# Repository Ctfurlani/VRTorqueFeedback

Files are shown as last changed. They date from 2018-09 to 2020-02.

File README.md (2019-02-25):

# VRTorqueFeedback
Software and Hardware to emulate haptic feedback of weighted objects in 
VR.

## Principle Of Operation
The idea is that the pointer (sometimes refered to as "feedback" in the 
code) moves/rotates in order to shift the center of mass of the
controller. This creates a torque that mimics the direction and
intensity of the one that would be exerted by the virtual object being
held.



## Calculating Pointer Position
If we imagine the feedback stem/pointer as a vector in R3, we can define
references and directions of motion to use in our program. In "home"
position, the vector points up, aligned with the Y axis. From this
position, it can rotate alpha degrees around the X axis, and Gamma
degrees around the Z axis, reaching any position in a hemisphere of
positive Y values.

We gain ease of understanding and implementation by decomposing the
ideal torque in two components Tx and Tz (projections over the X and Z
axis). To emulate Tx and Tz on the user's hand, the feedback must rotate
alpha degrees around X (for Tx), and gamma degrees around Z (for Tz).
The combination of these two rotations yields the sum of Tx and Tz,
which is the real torque T.

 

Ideal torque T will be achieved if and only if the pointer is rotated by
alpha and gamma, so the problem lies in calculating these two angles.
Luckily, the decomposition chosen facilitates this task by letting us
analyse torque decompositions with coplanar vectors *Rx*,*Wx* and *Rz*,
*Wx* - projections of R and W on X and Z.

We obtain ideal torque vector directly with

<!-- **T** = **R** x **W** -->
 

Then, we split it in two components, projections on X and Z:

<!-- TprojX = **T** . **X** = |**Tx**| * signX, where signX is 1 or -1 -->
 

<!-- TprojZ = **T** . **Z** = |**Tz**| * signZ, where signX is 1 or -1 -->
 

Where signx and signz follow the rule
 

We obtain the angles alpha' ang gamma' from the cross product magnitude
formula and considering that dot product is a linear operation (used to
calculate **Tx** and **Tz**).

<!-- |**Tx**| = |**Rx**| * |**Wx**| * sin(alpha') , where a E [0, 90] -->
 

<!-- |**Tz**| = |**Rz**| * |**Wz**| * sin (gamma') , where g E [0, 90] -->
 

 

We then solve for alpha' and gamma', while substituting |**Wx**| =
|**Wz**| = |**W**| for m * g (to account for real feedback weight);
|**Rx**| for rx * l; and |**Rz**| for rz * l (to account for real
feedback length, but keeping proportions between **Rx** and **Rz**).

<!-- alpha' = arcsin((|**Tx**|) / |**Rx**| * l * m * g) -->
 

<!-- gamma' = arcsin((|**Tz**|) / |**Rz**| * l * m * g) -->
 

 

We could simplify l * m * g to a single constant c, but it's useful to
have it separated into the two tangible variables l and m because of the
attribution of weights and distances in metric units in the virtual
scenario (in Unity they are actually dimensionless, but if we assume
meters for distance, we must also assume kilograms for mass).

Finally, we obtain alpha and gamma from alpha' and gamma', attributing
it the correct signs to achieve full hemispherical reach.

<!-- alpha = alpha' * signX, where alpha E [-90, 90] -->
 

<!-- gamma = gamma' * signZ, where gamma E [-90, 90] -->
 

 

### "Neutralizing" Center of Mass
When the user is not holding any object, the program can rotate the
feeeback pointer so that it shifts the controller's center of mass to a
position where (ideally) no torque would be exerted over the player's
hand. The heuristic to achieve this effect is to rotate the pointer
according to the rotation of the controller, in the opposite direction
of rotation around X and Z axes. As an example, if the user tilts the
controller by 30 degrees around the X axis and 45 degrees around the Z
axis, the pointer will rotate by -30 and -45 degrees (maybe multiplied
by a proportionality constant) around X and Z to compensate.

 

## Obtaining Angles for Servos
The angles alpha and gamma are not the ones to be used by the servo
motors. This is because the two DoFs of the motors are not the same as
the ones used in our previous calculations (rotations around X and Z
axes). The servos combine theta (angles from Z in the XZ plane) and phi
(angles from Y axis) rotations in spherical coordinates, with fixed
radius. This angles must be derived unambiguously from the position of
the feedback pointer, to provide the mirroring from the virtual pointer
to the real one.

<p align="center">
     
    
</p> 

## Moving the Servos
Movement of the servo motors is coordinated by the ARDUnity plugin. With
its "wire editor", we create a serial communication bridge between Unity
and an arduino. The serial communication transmits data to coordinate
two servos (represented by two "Generic Servo" components), which get
the desired angle of rotation from a direct mapping of the rotation of a
virtual object (with the components/scripts "Rotation Axis Reactor").
With this setup, to achieve rotations by X degrees in a servo, we simply
rotate a linked virtual object by X degrees in a set direction. In our
scene, these objects are the "Mirror Servo Theta" and "Mirror Servo
Phi".

<p align="center">
    
    
</p>

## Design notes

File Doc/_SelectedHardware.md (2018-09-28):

# Prototype 0 Hardware List

|Part |Quantity |Buy/Print  |File Name (inside Prototype1/Prototype0) |Link |
|---	 |:---:	 |:---: |---	 |---	 |
|Hitec HS-311 Servo |1 	 |Buy* |servo_hs_311 |https://goo.gl/PXjvbA  |
|Screw 04** - Lenght 0.1875" (3/16") |4 	 |Buy |actobotics/screw_632104 |https://goo.gl/LqVes7  |
|Screw 06** - Lenght 0.250" (1/4") |2 	 |Buy |actobotics/screw_632106 |https://goo.gl/LqVes7  |
|Screw 08** - Length 0.3125" (5/16") |2 	 |Buy |actobotics/screw_632108 |https://goo.gl/LqVes7  |
|Screw 10** - Length 0.375" (3/8") |3 	 |Buy |actobotics/screw_632110 |https://goo.gl/LqVes7  |
|Screw 20** - Length 0.750" (3/4") |2 	 |Buy |actobotics/screw_632120 |https://goo.gl/LqVes7  |
|Nut**	 |5 	 |Buy |actobotics/nut |https://goo.gl/WMunDN  |
|Std-Servo Plate A |1 	 |Print |actobotics/servo_plate_standard_a.par |https://goo.gl/hHZ4xE  |
|Hub Horn (disk) |2 	 |Print |actobotics/disco_hub_1.par |https://goo.gl/RcKKAo  |
|Pattern Bracket |1 	 |Print |actobotics/pattern_bracket_standard.par |https://goo.gl/cb6QCk  |
|Side Mount B |1 	 |Print |actobotics/side_mount_b.par |https://goo.gl/otaodq  |
|Aluminum Beam 6-16 |1 	 |Print |actobotics/beam_aluminum_vertical.par |https://goo.gl/EDe8Bq  |
|Custom Spacer |1 	 |Print |custom/custom_spacer |- |	

*Price: R$ 56,90 + R$ 20.90 (shipping)

**Thread size 6-32





# Prototype 1 Hardware List

## 3D print
### Strap
-  https://www.thingiverse.com/thing:1959237

    

- 3D print https://www.thingiverse.com/thing:2713178

    

### Shell
- 3D print shell coupled to strap

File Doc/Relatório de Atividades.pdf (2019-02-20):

# Relatório de Atividades

### Bolsa de Iniciação Científica CNPq

# 1. Identificação

## 1.1. Dados de Identificação do Projeto

Título do Projeto: Emulação de Torque em Ambientes de Realidade Virtual Vigência da Bolsa: 01/08/2018 a 28/02/2019
Período do Relatório: 01/08/2018 a 28/02/2019
Orientador: Prof. Dr. Anderson Maciel

## 1.2. Dados de Identificação do Bolsista

Nome: Gabriel de Souza Seibel
Vínculo Acadêmico: UFRGS - Graduando em Engenharia de Computação CPF: 872.043.550-91

# 2. Introdução

Interações entre usuários e ambientes de realidade virtual se baseiam, atualmente, em informações visuais e auditivas. O usuário, com a tecnologia de rastreamento atual, é capaz de manipular objetos virtuais através do uso de controles como o do HTC VIVE. Contudo, esse modelo deixa a desejar quanto ao potencial de imersão e realismo, pela falta de estímulos hápticos com os quais os humanos estão acostumados.
O projeto em questão tem como objetivo enriquecer interações com ambientes de realidade virtual através da criação de um acessório para o controle do HTC VIVE que provoca no usuário a impressão de que objetos manipulados causam torque em suas mãos (como acontece naturalmente na realidade). O uso do dispositivo proposto tem potencial não somente aumentar a imersão dos usuários, mas também de proporcionar manipulações mais precisas. O efeito de torque sobre a mão humana é atingido pelo deslocamento do centro de massa do acessório fixado ao controle que o usuário segura. Para tanto, o funcionamento do dispositivo é baseado em dois motores que giram e deslocam, nos limites de um hemisfério, uma haste com a ponta pesada.

# 3. Materiais e Métodos

O desenvolvimento do projeto se deu em etapas distintas; cada uma será abordada a seguir, aproximadamente em ordem cronológica. O progresso da implementação foi constantemente reportado e discutido com o professor orientador, de modo que passos seguintes pudessem ser estabelecidos de maneira eficiente e com segurança.

## 3.1. Definição e Modelagem do Problema e da Solução

Em um primeiro momento, foi necessário definir precisamente qual seria a motivação e o objetivo do projeto. O produto foi imaginado de maneira relativamente precisa, e sua especificação de funcionamento foi definida em vários aspectos. A interação entre motores e o ambiente virtual foi minuciosamente planejada, evidenciando as ferramentas, as abstrações e os cálculos matemáticos a serem empregados na implementação do objetivo principal (a emulação de torques causados por objetos que o usuário segura).
Nesta etapa, foram elencados itens essenciais para a realização do projeto: dois servos motores, um simulador na plataforma Unity, uma placa Arduino (para controle dos servos e comunicação com a Unity) e uma “presilha” para acoplar os servos e a placa no controle do HTC VIVE de forma modular e prática (este item seria confeccionado no laboratório com o auxílio de uma impressora 3D).

## 3.2. Estudo de Trabalho Prévio e Ferramentas

Com o problema e a solução mais precisamente delineados, partiu-se para o estudo de um trabalho prévio de outra bolsista no mesmo projeto. Esta etapa foi importante pela identificação de ferramentas auxiliares que poderiam ser utilizadas para facilitar o desenvolvimento. Mais precisamente, foi entendido que a maneira mais prática de integrar a placa Arduino com a Unity seria usando um plugin que a bolsista havia prospectado e explorado - chamado ARDUnity.
Em seguida, alguns dias foram dedicados ao aprendizado do uso da Unity, através de vídeos tutoriais e implementações de jogos e simulações simples. Houve, concomitantemente, familiarização com a linguagem de programação C#, empregada para a criação dos projetos de estudo. Mais adiante, o plugin SteamVR foi testado e explorado para que houvesse a integração do HTC VIVE com a simulação a ser implementada. Também foi atestado o funcionamento do plugin ARDUnity, comprovando a comunicação efetiva entre o software e o microprocessador da placa.

## 3.3. Hardware

### 3.3.1. Circuito Elétrico

A fim de proporcionar o funcionamento correto, seguro e performaticamente satisfatório dos servos motores, foi necessário elaborar um circuito elétrico simples envolvendo esses componentes, o Arduino e baterias. O circuito originalmente foi imaginado sobre uma placa de prototipação (documentado utilizando o software Fritzing, como mostra a Figura 1), mas em iterações posteriores alguns fios foram soldados e arranjados de forma que a protoboard não fosse mais necessária.

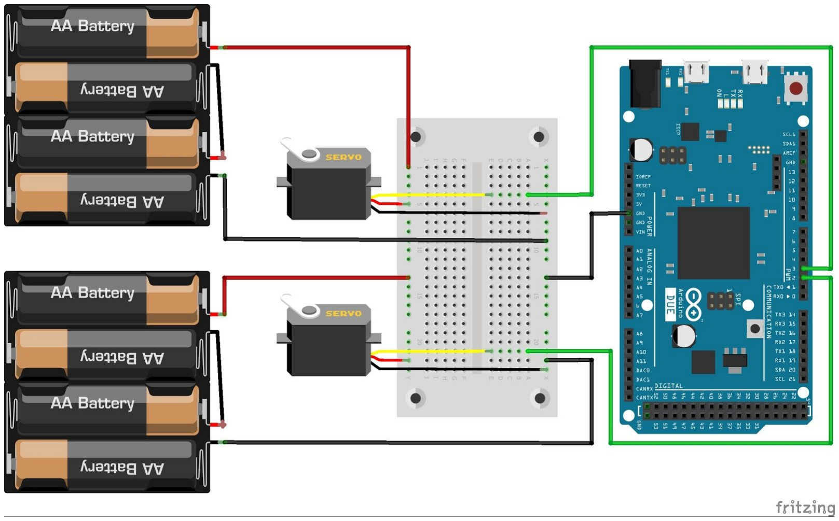
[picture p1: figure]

Figura 1 - Protótipo de circuito no software Fritzing.

Também foi explorado o funcionamento de um componente eletrônico que provesse comunicação sem fio entre o Arduino e o computador onde é executada a simulação, para ser usada em vez da comunicação por cabo USB. Apesar de atestado o funcionamento do novo meio de comunicação, o desenvolvimento dessa funcionalidade foi postergado devido a impossibilidade de integração do módulo com a Unity em um curto espaço de tempo sem que fosse paga uma taxa pelo serviço do plugin ARDUnity.

### 3.3.2. Peças Rígidas - Impressora 3D

Tendo pronta a integração entre os motores e o software, era chegado o momento de criar partes rígidas que tornassem o produto integrável ao controle do VIVE. A modelagem das peças foi realizada no software Solid Edge (como mostra a Figura 2), após uma etapa de aprendizado do uso da ferramenta através de vídeos e tutoriais práticos. Dificuldades e dúvidas pontuais do uso do programa (e futuramente da impressora 3D) foram resolvidas recorrendo ao auxílio de um mestrando do laboratório que possuía experiência na área.
Em um primeiro momento, foram modeladas partes para fixar um motor ao outro, associando seus eixos de rotação de modo que a haste pudesse ser girada até qualquer ponto de uma semi-esfera imaginária (possibilitando o deslocamento do centro de massa do sistema). Em seguida, em uma segunda etapa, foi projetada uma presilha para acoplar os sistema haste-motores e o Arduino ao controle do HTC VIVE, etapa que demandou maior empenho e tempo de dedicação do que a primeira.

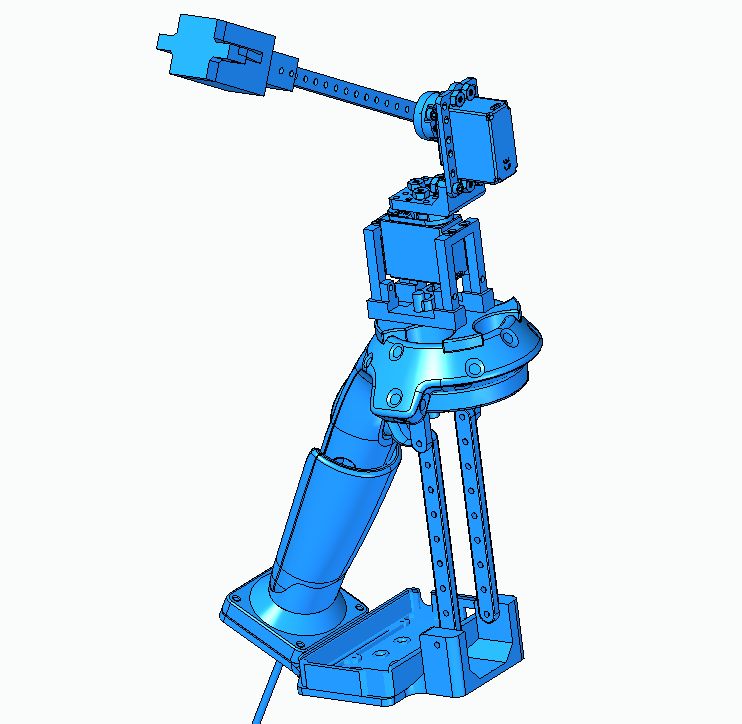
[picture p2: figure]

Figura 2 - Protótipo no software de modelagem Solid Edge.

A medida que as peças eram definidas, projetadas e integradas em software, tornava-se possível imprimi-las no laboratório com a impressora 3D. Ambas as etapas tiveram numerosas iterações e mudanças, a fim de proporcionar um produto adequado aos requisitos funcionais e não-funcionais do projeto. Contudo, ao mesmo tempo constantemente visava-se minimizar custos de materiais de impressão e de energia elétrica pelo uso da impressora.

## 3.4. Software

Seguindo boas práticas de implementação e possibilitando melhor organização no projeto, utilizou-se um repositório Git para manejo de versionamento e armazenamento remoto, disponível em https://github.com/gabrielseibel1/VRTorqueFeedback. O funcionamento do software é explicado mais detalhadamente no arquivo README.md do repositório, a fim de que futuros colaboradores possam se familiarizar rapidamente com o projeto e a solução empregada. Contudo, vale ressaltar aqui alguns pontos chave da implementação.
Utilizando os cálculos elaborados no início do desenvolvimento do projeto, o programa é capaz de identificar em que posição a haste pesada deve ser posicionada para emular fielmente o torque esperado por segurar um objeto. O cálculo considera as posições e rotações da mão do usuário e do objeto virtual, juntamente com a massa do objeto. A posição desejada da haste é então considerada para o posicionamento dos motores, que são abstraídos por cilindros virtuais que tem sua rotação alterada pelo programa e mapeada para os servos pelo ARDUnity. Posteriormente, foram adicionadas novas funcionalidades como a neutralização do torque quando nenhum objeto está sendo manipulado.

# 4. Resultados

Durante o período da bolsa de iniciação científica, foi desenvolvido, do ínicio, um produto integrando hardware e software. O protótipo, mostrado na Figura 3, consegue exercer torque sobre a mão do usuário de modo satisfatório, além de ser acoplado ao HTC VIVE com mobilidade e segurança adequadas. É destacado o potencial uso do acessório para pesquisas científicas relacionadas a imersão e performance em atividades em ambientes virtuais, além da possibilidade da criação de extensões e aprimoramentos (como o uso do módulo wifi/wireless) que podem torná-lo mais apelativo para, entre outros fins, até comercialização.
Houve, mais do que qualquer outro ganho, aprendizado. Familiaridade com tecnologias de criação de jogos/simuladores e de peças rígidas e prática de integração entre hardware e software, além de experiência acadêmica (particularmente na interessantíssima área de háptica) foram fortes pilares de desenvolvimento pessoal construídos ao longo do desenvolvimento do projeto.

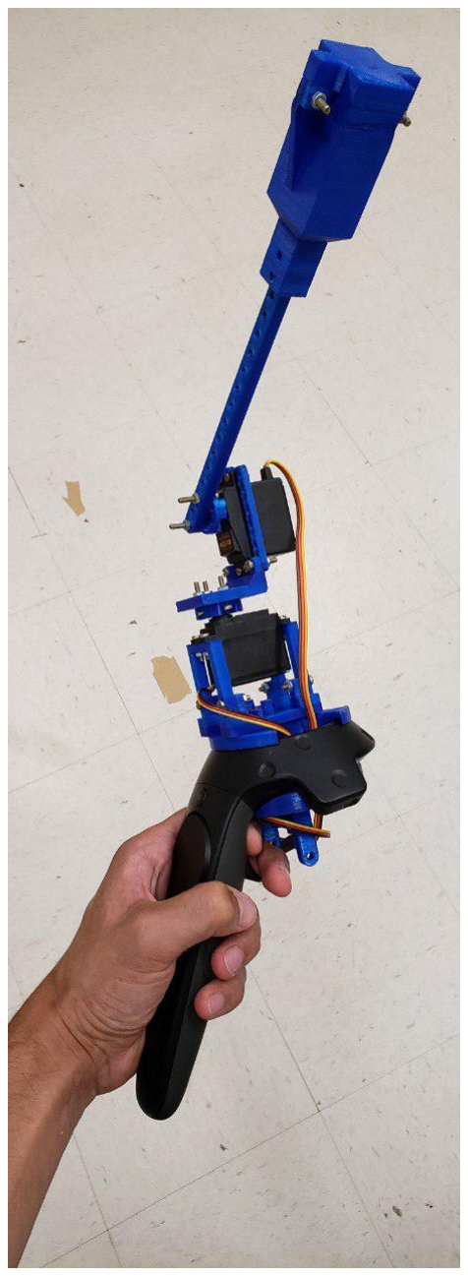
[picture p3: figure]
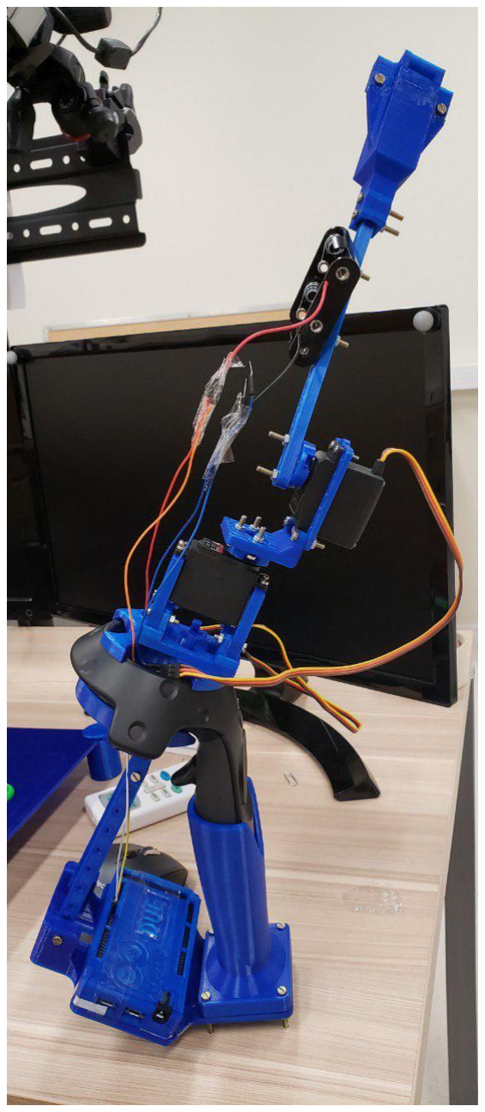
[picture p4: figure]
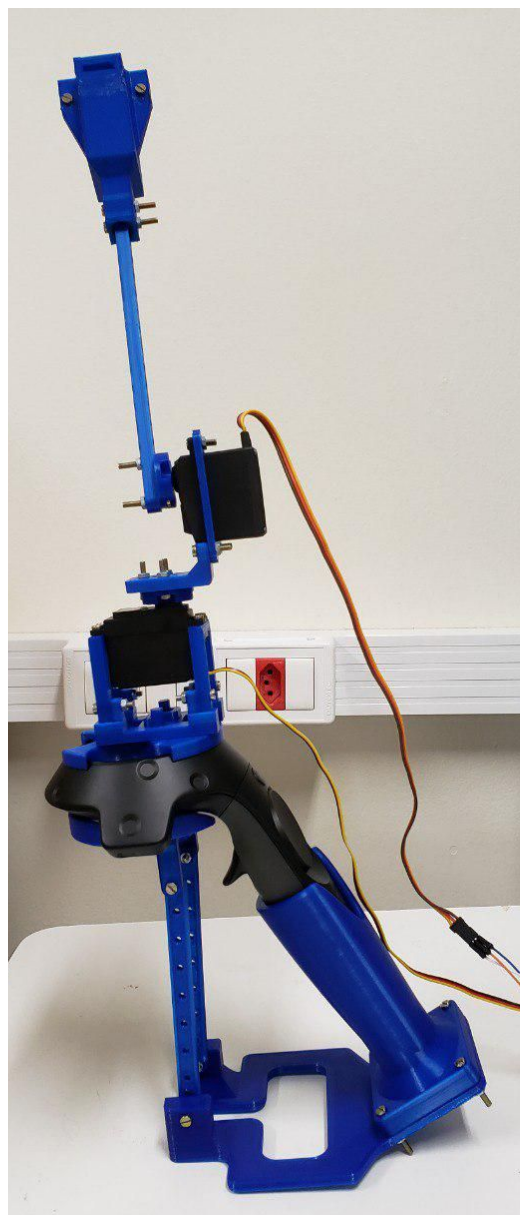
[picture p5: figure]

Figura 3 - O protótipo acoplado ao controle do HTC VIVE.

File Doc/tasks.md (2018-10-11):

# Tasks

## Docking
Spawn objects in different places (maybe a big shelf?), so the user can manipulate them and we make sure he is not biased/conditioned with the positions.

Maybe a separate task for time and precision?
Catalog: time and precision (how far from ideal position, for each dimension)

## Ordering
N objects are spawned, to be positioned, in order of weight, in N spacious slots / areas.
The user is informed there can be objets with the same weight. If the user can't distinguish the weight of some objects, or he thinks they are the same weight, they should be positioned in the same order/slot/area.

Change N to analyse "resolution" of the system (how many weights can the user distinguish?): 3, 5, ...
Catalog: time and order/positioning

___

### Considerations
Play with textures, sizes and shapes? Sometimes correspondence between weights and textures, sometimes not. Can we fool visual influence?

### Future Tasks
#### Stacking
Catalog: time (total and per object, for each layer) and #objects stacked until fall. Wait for collision feedback to be implemented.

posicionar (docking) e compara��o de pesos pura (ordenar objetos por peso, brincar com texturas e formatos, tamanhos - as vezes corresponder ou nao, e ver quanto o visual tem influencia, se conseguimos vencer essa influencia)

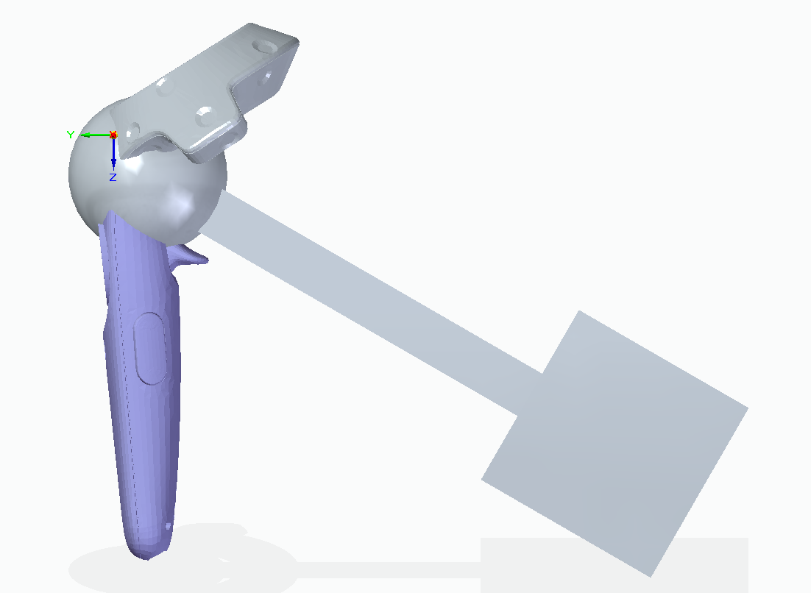
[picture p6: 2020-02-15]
Hardware/Schems/vive_controller_angle.PNG

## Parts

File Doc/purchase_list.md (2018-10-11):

# Purchase List

## Electronics
1. 12x AA alkaline batteries (power servos)

## Hardware
|Part |Quantity |Link |
|---	 |:---:	 |---	 |
|Parafuso altura 0.1875" (3/16") |4 	 |https://goo.gl/LqVes7  |
|Parafuso altura 0.250" (1/4") |2 	 |https://goo.gl/LqVes7  |
|Parafuso altura 0.3125" (5/16") |2 	 |https://goo.gl/LqVes7  |
|Parafuso altura 0.375" (3/8") |3 	 |https://goo.gl/LqVes7  |
|Parafuso altura 0.750" (3/4") |2 	 |https://goo.gl/LqVes7  |
|Nut	 |5 	 |https://goo.gl/WMunDN  |

Thread size 6-32







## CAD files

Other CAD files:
Hardware/Printing/arduino_due_case_top.stl
Hardware/Printing/arduino_due_case_bottom.stl

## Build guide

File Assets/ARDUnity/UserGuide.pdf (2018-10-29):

Thank you for using ARDUnity.

For more information, visit below link, please.

## (https://sites.google.com/site/ardunitydoc/)

# What is ARDUnity?

# - ARDUnity is an asset that can make Unity App to

interact with Arduino.

# - ARDUnity is a compound word of “Arduino + Unity”

# ARDUnity Edition Comparison

Features | Basic | Deluxe
Price | Free | $55
Wire Editor | Yes | Yes
Support PlayMaker | Yes | Yes
ARDUINO Board (Included compatible product) | Yes | Yes
Digital I/O (Digital Read/Write) | Yes | Yes
PWM (Analog Write) | Yes | Yes
ADC (Analog Read) | Yes | Yes
Servo Motor (Only controlling PWM) | Yes | Yes
Tone (Buzzer) | Yes | Yes
Bluetooth LE (HM-10) | No | Yes
DC Motor Driver (ex, Motor Shield) | No | Yes
Bluetooth Classic (ex, HC-06) | No | Yes
TCP/IP (ex, WiFi Shield, ESP8266) | No | Yes
Utilities for Smart Phone (Android/iOS) | No | Yes
AHRS Sensor (ex, MPU6050) | No | Yes
Support various product for ARDUINO | No | Yes

For newest information (https://sites.google.com/site/ardunitydoc/home/release-note)

# How it works?

Add Component using Wire Editor | Export Arduino Sketch

Upload sketch to Arduino Board

Play in Unity3D Editor
&
Connect ArdunityApp

Build Arduino Circuit

# Supported connections

Arduino Hardware

Bluetooth

WiFi

PC

Tablet

Smart Phone

※ Some connections may not yet supported and may require additional hardware Arduino.

# Resolve error

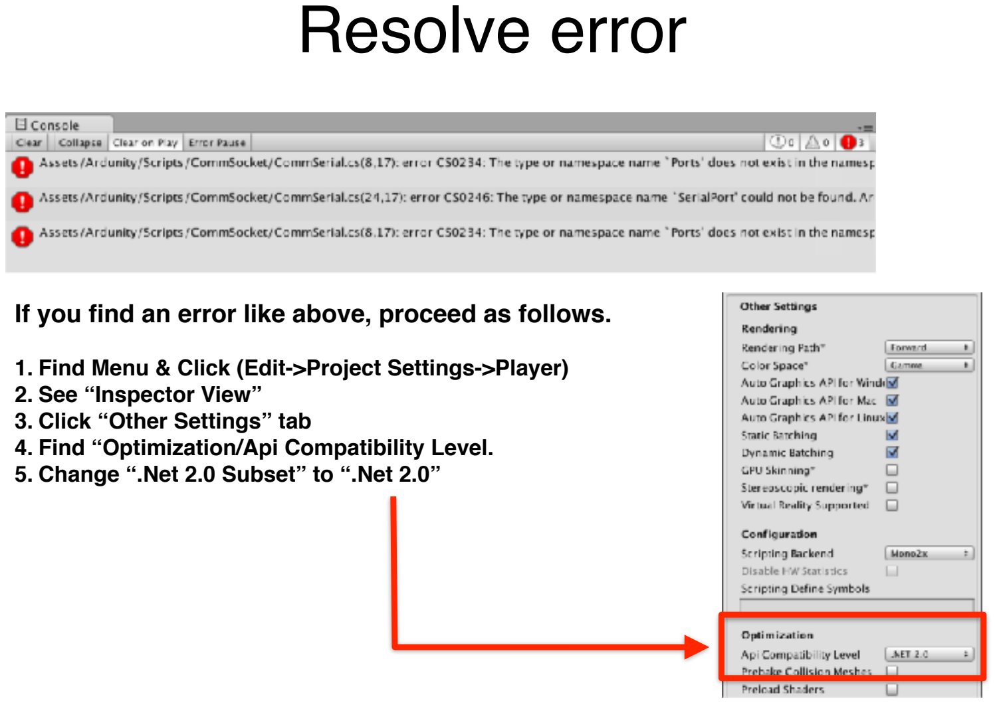
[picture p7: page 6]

If you find an error like above, proceed as follows.

### 1. Find Menu & Click (Edit->Project Settings->Player) 2. See “Inspector View” 3. Click “Other Settings” tab

4. Find “Optimization/Api Compatibility Level.

### 5. Change “.Net 2.0 Subset” to “.Net 2.0”

# You need to Arduino

# - Download & Install “Arduino IDE”

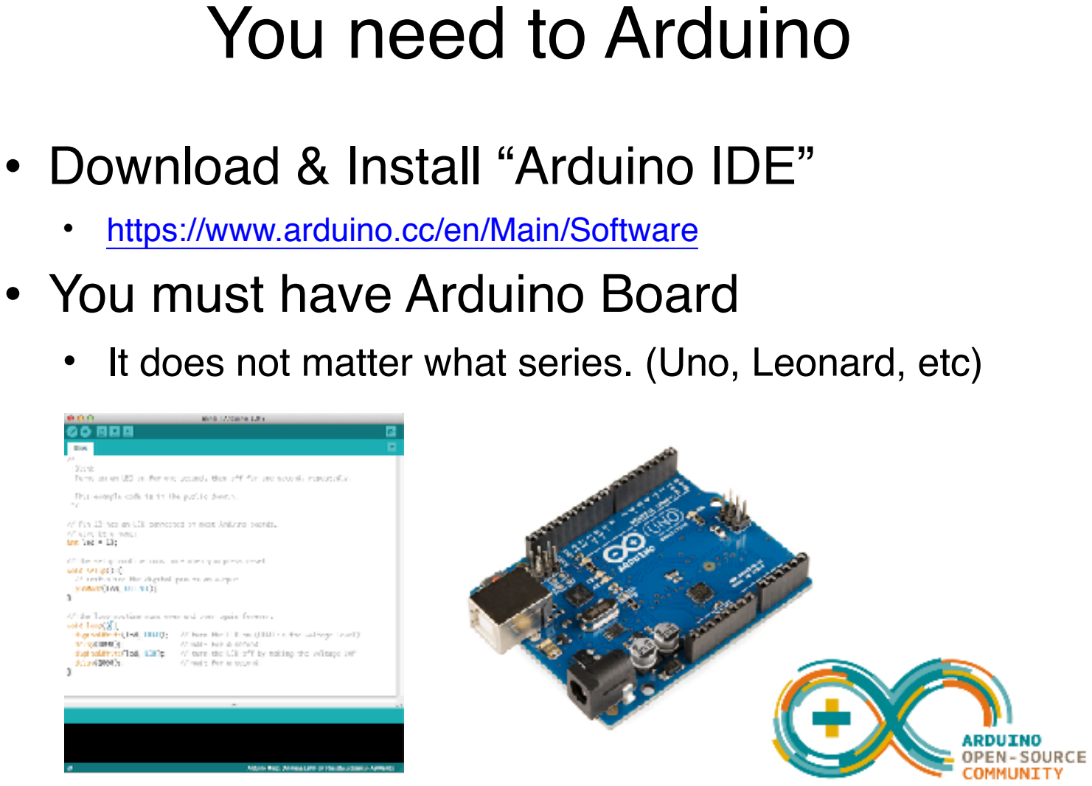
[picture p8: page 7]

## - https://www.arduino.cc/en/Main/Software

# - You must have Arduino Board

# - It does not matter what series. (Uno, Leonard, etc)

# ARDUnity Architecture

Arduino | Unity

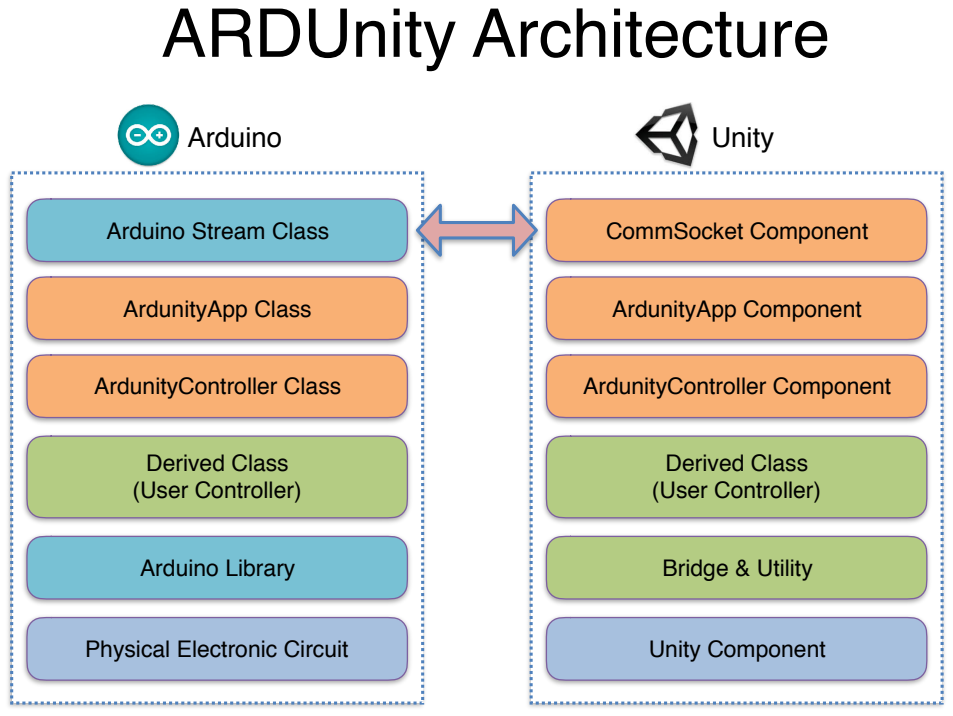
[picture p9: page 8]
ArdunityApp Class; ArdunityController Class; Arduino Library; Derived Class (User Controller); CommSocket Component; ArdunityApp Component; ArdunityController Component; Unity Component; Bridge & Utility

Arduino Stream Class

Physical Electronic Circuit

# How to use Wire Editor (1/2)

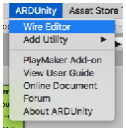
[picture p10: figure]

Open Wire Editor

Create Empty GameObject
&
Select it

Click mouse right button

The block is appeared
&
The component is added

If you want to remove, select and click mouse right button.

# How to use Wire Editor (2/2)

Drag a node in bold font

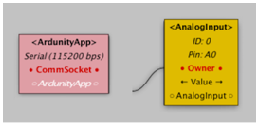
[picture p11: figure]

Possible connection node is displayed in white

Completed wiring

# Build for Android

- You need to modify manifest file to use bluetooth on Android.

# - Since the modified manifest file is existed in ARDUnity, you

have to copy it to a specified location.

# - From: ARDUnity/Plugins/Android/AndroidManifest.xml - To: Plugins/Android/AndroidManifest.xml

# Build for Android

# - If you already use the modified manifest file, you should insert

some content to existed manifest file.

# Support

- Please visit.

## - YouTube (https://www.youtube.com/channel/UCA3j4X_ic1wih0z0xs5LgTg/videos) - Online Document (https://sites.google.com/site/ardunitydoc/) - Forum (https://groups.google.com/forum/#!forum/ardunity-forum)

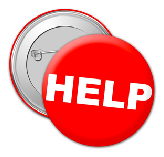
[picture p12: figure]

# Circuits for Example

# LED Circuit (Digital)

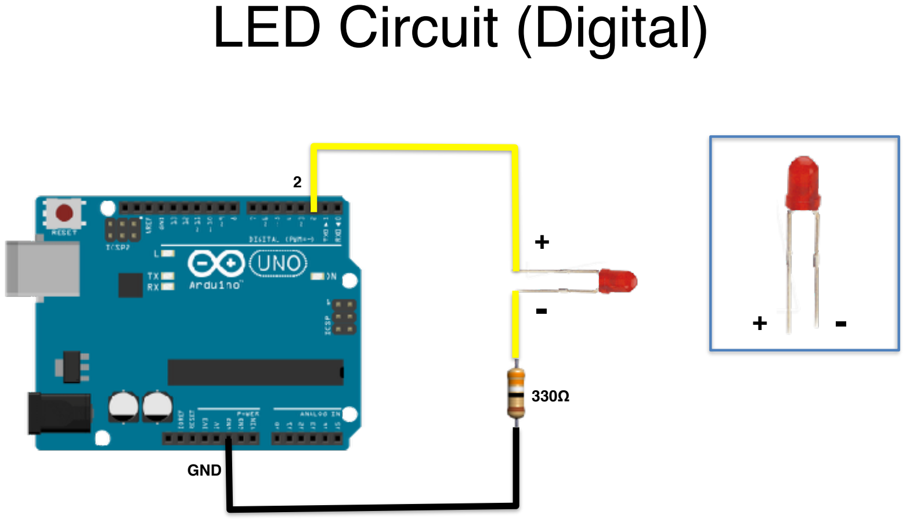
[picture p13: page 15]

2

GND

330Ω

+

- | + | -

# LED Circuit (Analog)

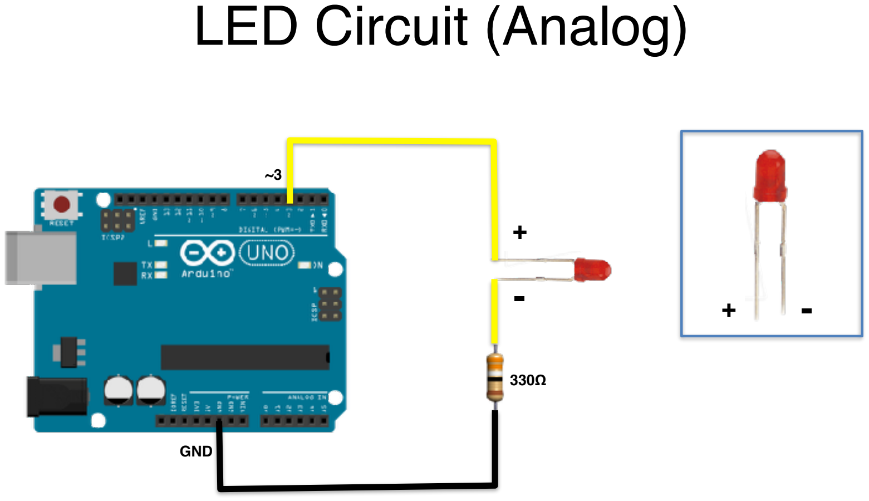
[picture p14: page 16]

~3

GND

330Ω

+

- | + | -

# Push Button Circuit (Use external VCC)

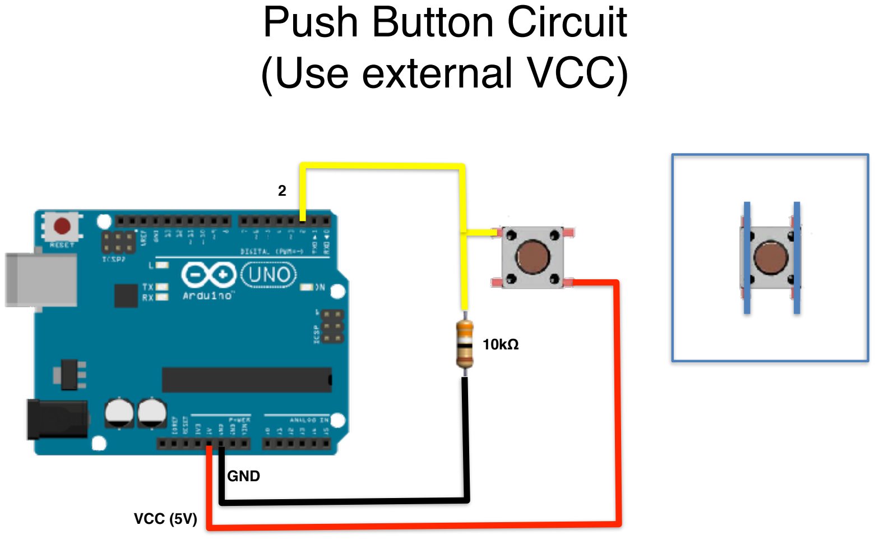
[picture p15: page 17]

2

GND

10kΩ

VCC (5V)

# Push Button Circuit (Use internal pull-up)

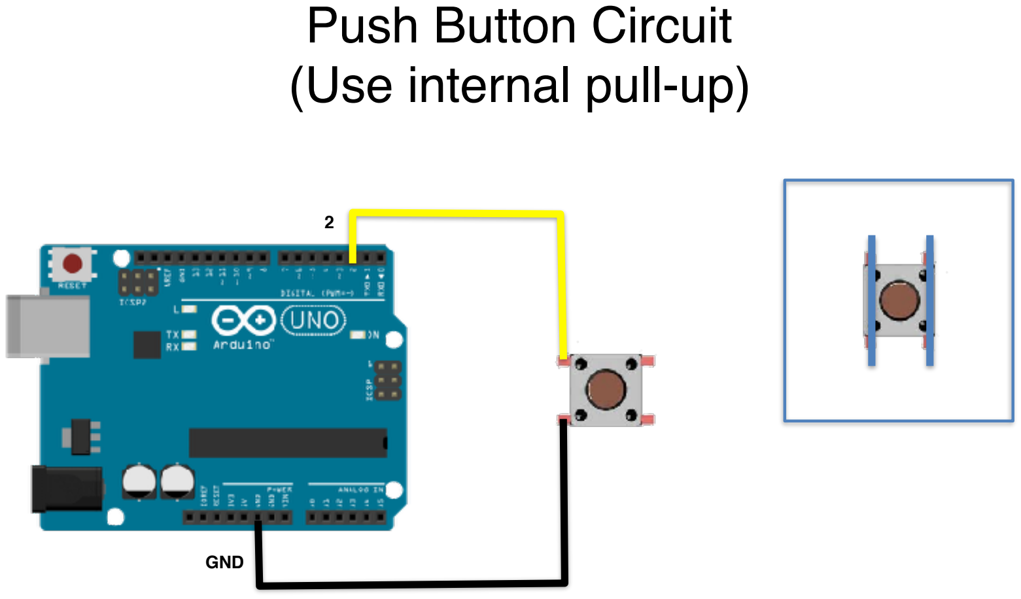
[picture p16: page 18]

2

GND

# RGB LED Circuit (Digital)

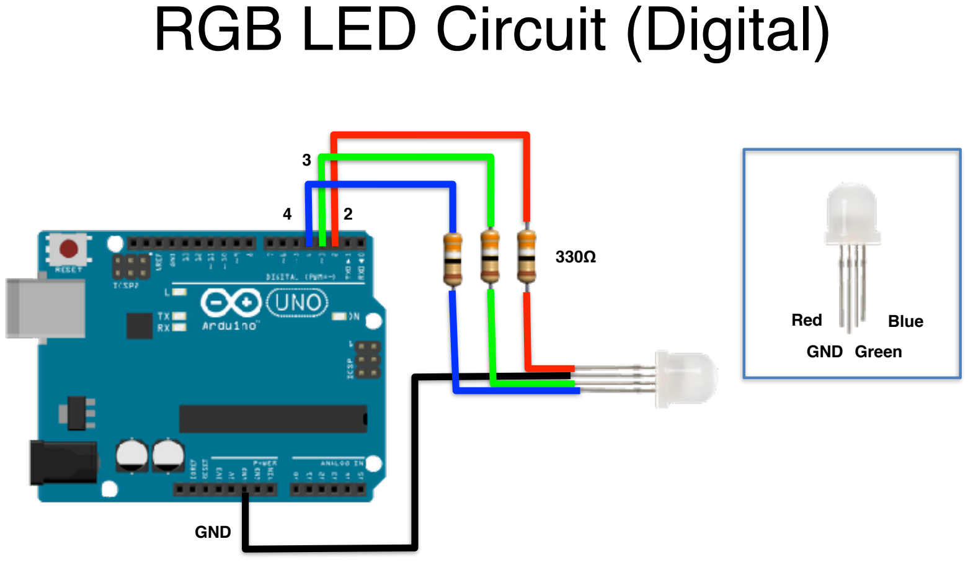
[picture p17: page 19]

Red

GND Green

Blue

330Ω

GND

2

3

4

# RGB LED Circuit (Analog)

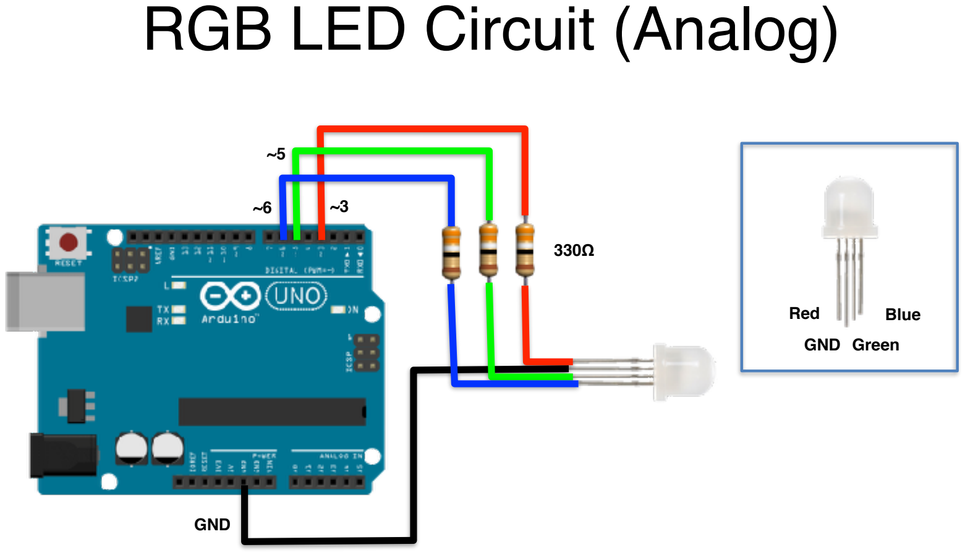
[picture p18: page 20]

Red

GND Green

Blue

330Ω

GND

~3

~5

~6

# Potentiometer Circuit

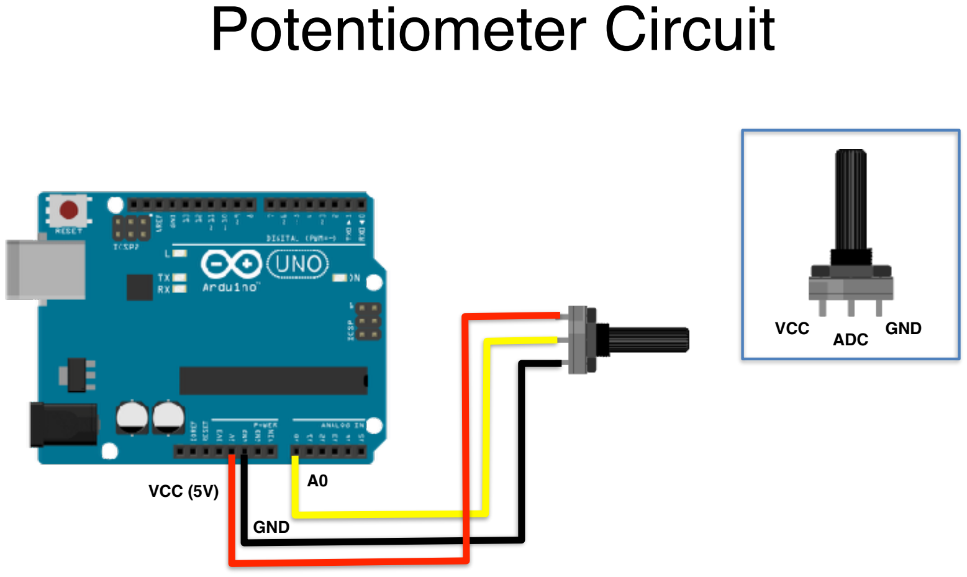
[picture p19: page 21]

VCC ADC GND

GND

A0 VCC (5V)

# Soft Potentiometer Circuit

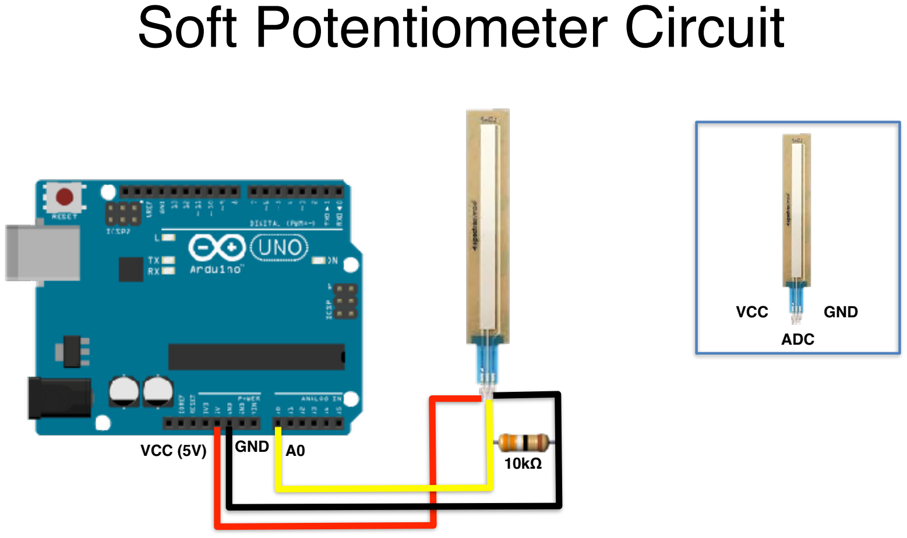
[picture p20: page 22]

VCC

ADC

GND

10kΩ VCC (5V) | GND | A0

# Photo Cell Circuit

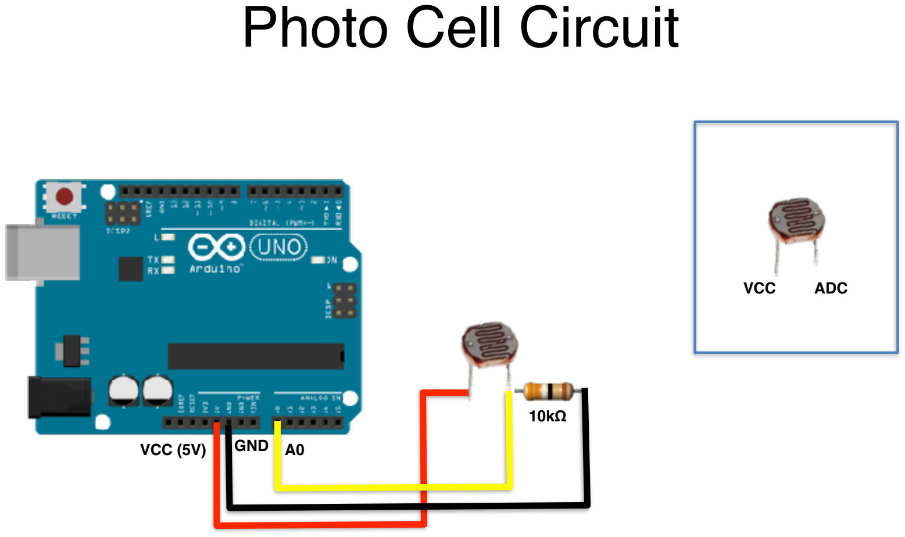
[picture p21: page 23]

VCC ADC

10kΩ

VCC (5V) | GND | A0

# Flex Sensor Circuit

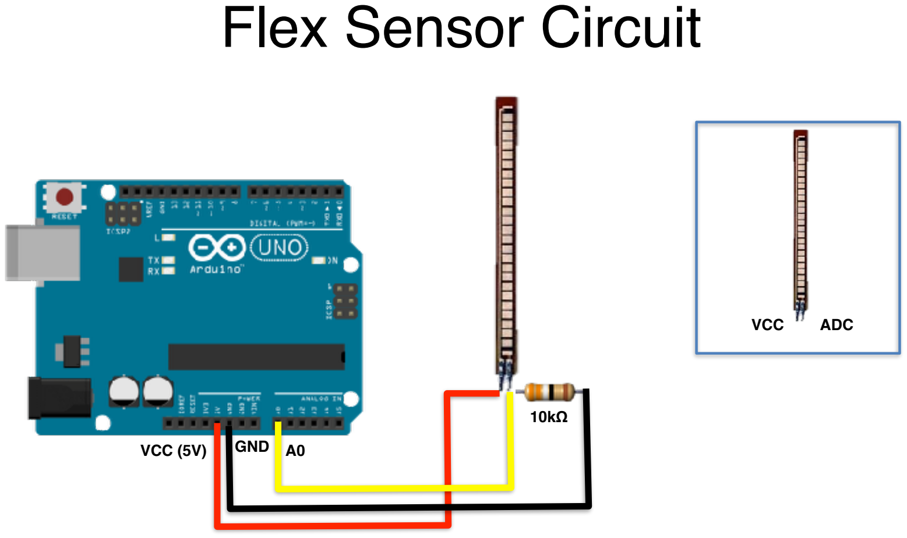
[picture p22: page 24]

VCC ADC

10kΩ

VCC (5V) | GND | A0

# TMP36 Circuit

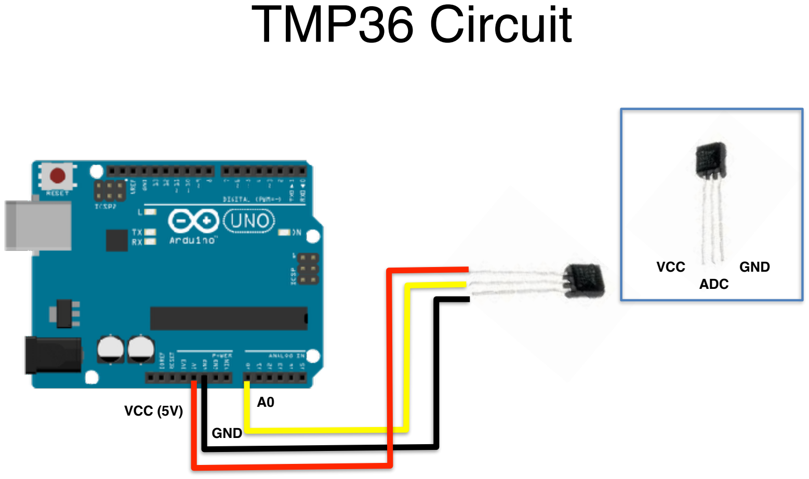
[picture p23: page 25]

VCC
ADC

GND

GND

A0 VCC (5V)

# Piezo Sensor Circuit

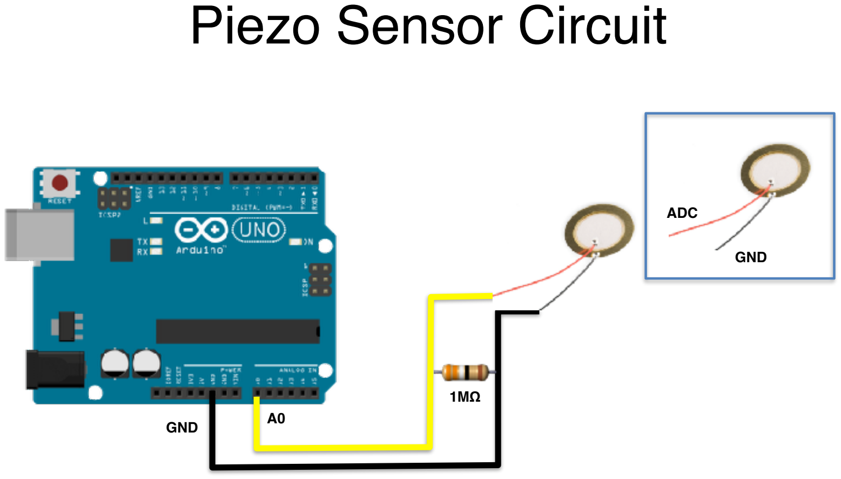
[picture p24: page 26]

ADC

GND

GND | A0

1MΩ

# Servo Motor Circuit

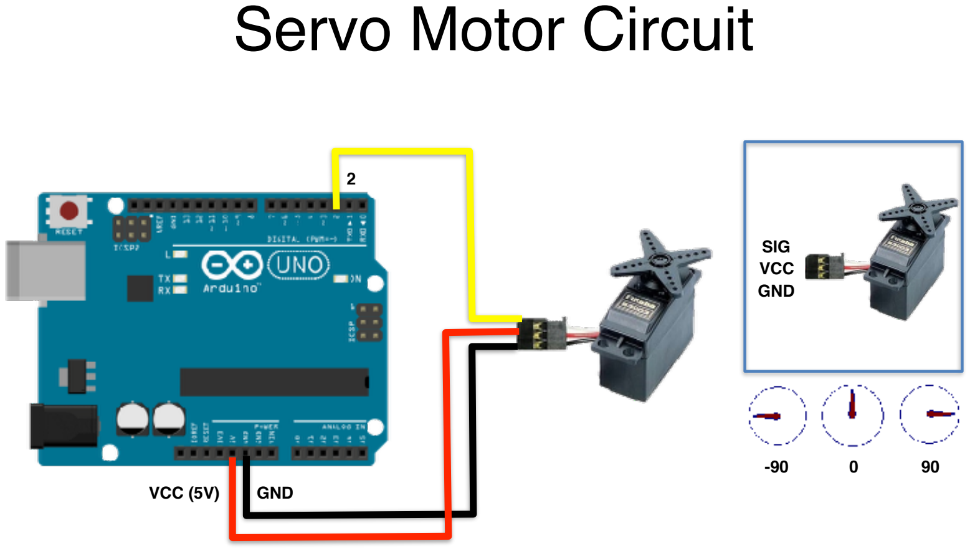
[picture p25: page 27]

SIG
VCC
GND
-90 | 0 | 90
VCC (5V) | GND

2

# Buzzer Circuit

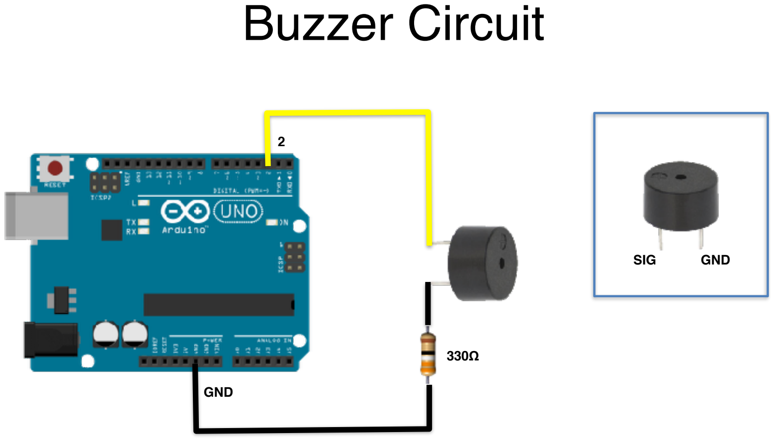
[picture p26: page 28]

SIG | GND

330Ω

2

GND

# Motor Shield Circuit

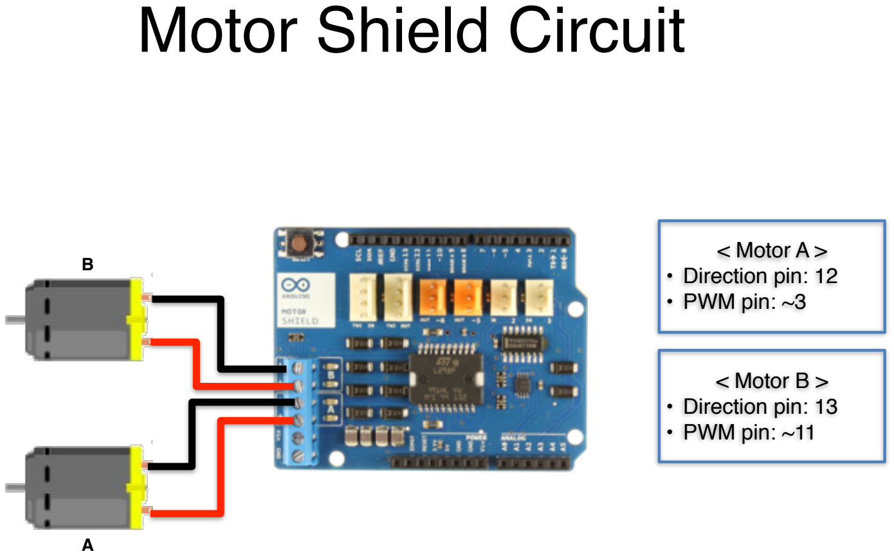
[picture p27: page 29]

### < Motor A > - Direction pin: 12 - PWM pin: ~3

### < Motor B > - Direction pin: 13 - PWM pin: ~11

B

A

# HC-06 Circuit

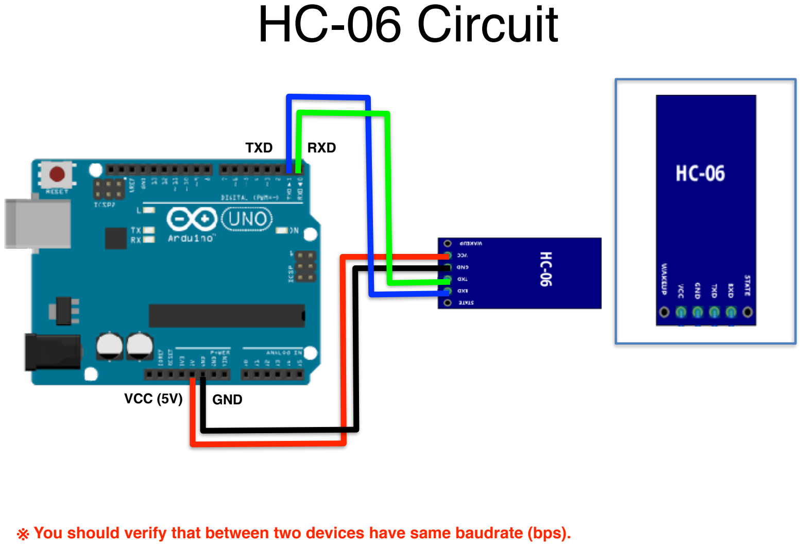
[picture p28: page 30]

VCC (5V) | GND
TXD | RXD

※ You should verify that between two devices have same baudrate (bps).

# MPU Series Circuit

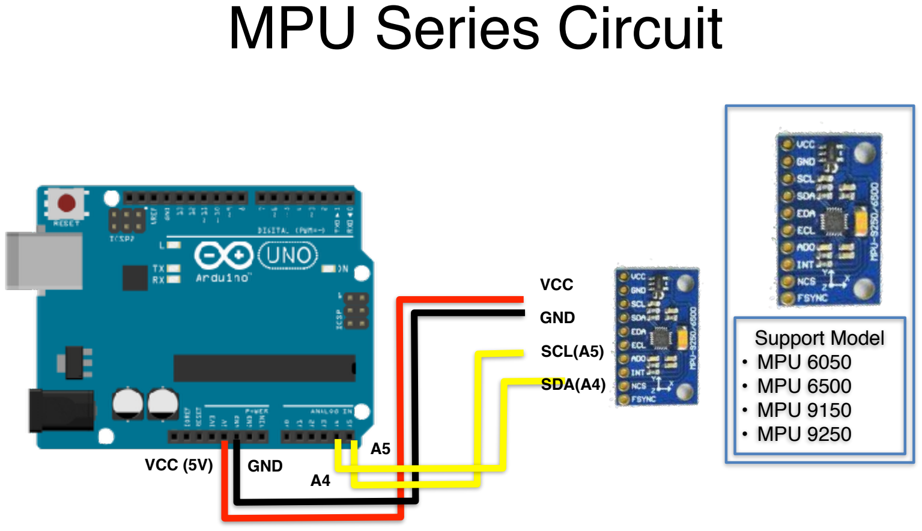
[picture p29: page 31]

VCC (5V) GND

A5

### Support Model - MPU 6050 - MPU 6500 - MPU 9150 - MPU 9250

VCC

GND

SCL(A5)

SDA(A4)

A4

# MPU Series Orientation

Coordinate System in Unity

Y -> Forward (Z)

X -> Right (X)

Z -> Up (Y)

Coordinate System in MPU

※MPUSeries convert a coordinate system between MPU and Unity. So, you can just think of MPU as Unity.

# Joystick Circuit

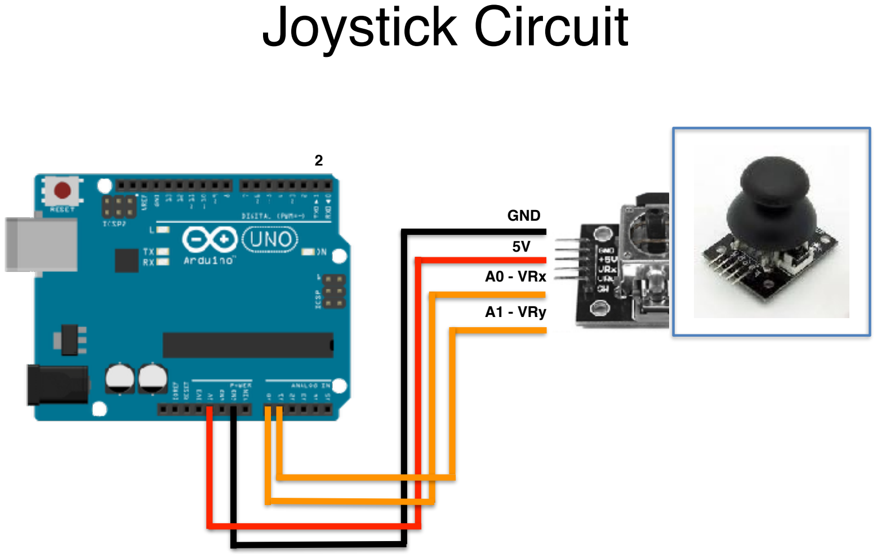
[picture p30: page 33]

5V

A0 - VRx

A1 - VRy

2

GND

# Appendix

# UNO Timer Conflict

## Timer 0 (8bit)

## Timer 1 (16bit)

## Timer 2 (8bit)

## GenericServo

## GenericTone

### Pin: ~5, ~6 AnalogOutput GenericMotor

Conflict (Can’t use together)

Conflict (Can’t use together)

### Pin: ~9, ~10 AnalogOutput GenericMotor

### Pin: ~3, ~11 AnalogOutput GenericMotor

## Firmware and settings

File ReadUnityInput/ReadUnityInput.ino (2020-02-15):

#include <Servo.h>

Servo servoPhi;
Servo servoTheta;

const byte numChars = 32;
char receivedChars[numChars];
char tempChars[numChars];        // temporary array for use when parsing
boolean newData = false;

int phiRotation = 90;
int thetaRotation = 90;

void setup() {
  Serial.begin (9600);
  servoPhi.attach(2);
  servoTheta.attach(5);
  
}


void loop()
{

  recvWithStartEndMarkers();
  if (newData == true) {
      strcpy(tempChars, receivedChars);
          // this temporary copy is necessary to protect the original data
          //   because strtok() used in parseData() replaces the commas with \0
      parseData();
      moveServos(phiRotation, thetaRotation);
      newData = false;
  }
  /*
  //Must delay 1 milliseconds to make Serial.available() work properly
  delay(1);

  //Serial.setTimeout(0);

  if ( Serial.available() >= 2) {

    servoInputAngles= Serial.readString();
    Serial.println(servoInputAngles);
    //moveServos(servoInputAngles[0],servoInputAngles[1]);
  }*/


}

void parseData() {      // split the data into its parts

    char * strtokIndx; // this is used by strtok() as an index

    strtokIndx = strtok(tempChars,",");      // get the first part - the phi rotation
    phiRotation = atoi(strtokIndx);     // convert this part to an integer

    strtokIndx = strtok(NULL, ","); // this continues where the previous call left off
    thetaRotation = atoi(strtokIndx);     // convert this part to an integer

}

void recvWithStartEndMarkers() {
    static boolean recvInProgress = false;
    static byte ndx = 0;
    char startMarker = '<';
    char endMarker = '>';
    char rc;

    while (Serial.available() > 0 && newData == false) {
        rc = Serial.read();

        if (recvInProgress == true) {
            if (rc != endMarker) {
                receivedChars[ndx] = rc;
                ndx++;
                if (ndx >= numChars) {
                    ndx = numChars - 1;
                }
            }
            else {
                receivedChars[ndx] = '\0'; // terminate the string
                recvInProgress = false;
                ndx = 0;
                newData = true;
            }
        }

        else if (rc == startMarker) {
            recvInProgress = true;
        }
    }
    //Serial.println(phiRotation);
}


void moveServos(int phiAngle, int thetaAngle){
  servoPhi.write(phiAngle);
  servoTheta.write(thetaAngle);
  
}

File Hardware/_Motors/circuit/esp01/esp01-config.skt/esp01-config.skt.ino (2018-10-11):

#define ESP8266_BAUD 9600

void setup()
{
  Serial.begin(ESP8266_BAUD);
  Serial2.begin(115200);

  delay(1000);
  Serial.flush();
}

void loop()
{
  while(Serial.available())
  {
    Serial2.write(Serial.read());
  }
  while(Serial2.available()) {
    byte b = Serial2.read();
    Serial.write(b);
  }
}

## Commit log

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2018-08-21 Integrate VIVE kit.
    Interactions with VR hands trigger torques on the feedback. Floor is now covered by teleport area. Added a useful reset scenario button and a pointer to the feedback sphere, so it can be better visualized.
2018-08-22 Make calculations be relative to hand rotation
    Consider the rotation of the hand when choosing a component for the torque. In other words, the X, Y and Z components of the torque should be X', Y' and Z', the axis of the transform of the hand. A simple rotation was used to fix this.
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2018-08-24 Resolve #3 - Create Prototype1 files
2018-08-27 Fix #1 - Unified Controller script: use one hand at a time
    Before, there was one script attached to each hand. This caused conflicting input to the feedback system, resulting in wrong angles when in mode.
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2018-09-11 Close #13 - Add assembly of 2 servos
    This assembly includes a connecting bridge and an axis aligner, for
    future connection of a spindle.
    [prototype_0.cfg, servo_and_bridge.cfg]
2018-09-11 Tackle #17 - Model strap
    [asm_strap.cfg]
2018-09-11 Subtract controller from strap
    [asm_strap.cfg]
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2018-09-14 Reorganize directories structure
    [asm_shell_and_controller.cfg, asm_strap.cfg, prototype_0.cfg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]
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2018-09-18 Model Prototype 0 with actobotics components
    [asm_hs311_servo_plate.cfg, prototype_0_actobotics.cfg, prototype_0_custom.cfg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]
2018-09-19 Add all needed fasteners in Prototype 0
    [prototype_0_actobotics.cfg]
2018-09-19 Grouping bolts in assembly
    [prototype_0_actobotics.cfg]
2018-09-21 Add hub horn, spacer and beam to prototype 0
    [prototype_0_actobotics.cfg]
2018-09-21 Group parts related to spindle
    [prototype_0_actobotics.cfg]
2018-09-21 Rename nut file from "bolt" to "nut"
    [prototype_0_actobotics.cfg]
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2018-09-27 Generated .STL for each part to be printed
    Used 0.001 tolerance (fine) for parts with screw holes or more details,
    and 0.01 for the less complex ones.
    [beam_aluminum_6_16.stl, custom_spacer.stl, disco_hub_1.stl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]
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2018-10-04 Fix unmoving servos
    Change servo's reference to feedback - from feedback sphere to whole
    feedback system.
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2018-10-08 Make servo power and control circuit
    [servo_circuit.fzz]
2018-10-17 Add new version of prototype 0 assembly
    New version has stronger hinge and has all the required nuts.
    [asm_hs311_servo_plate.cfg, prototype_0_actobotics.cfg, prototype_0_actobotics_v2.cfg]
2018-10-17 Solid Edge unnecessary save
    [asm_hs311_servo_plate.cfg, prototype_0_actobotics_v2.cfg]
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2018-10-29 Update printing folder with new parts
    [90-single-angle-short-channel-bracket.stl]
2018-10-29 Restructure directories and add "board" parts
    [arduino_and_breadboard_with_limiter.cfg, asm_hs311_servo_plate.cfg, circuit_plane_with_circuit.cfg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]
2018-11-07 Move printing folder up and add stls for bumper
    [---threaded_bumper_top---.stl, ---vive_bumper_base_final---.stl, 90-single-angle-short-channel-bracket.stl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]
2018-11-07 First complete 3D model of Prototype1
    [Asm1.cfg, pillars_tower.cfg, prototype_1.cfg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]
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2018-11-08 Add complete version of controller in new folder
    [vive_controller.cfg]
2018-11-08 Add files for custom bottom grip
    [controller_and_custom_bottom_grip.cfg]
2018-11-08 Make angled base on bottom grip
    [controller_and_custom_bottom_grip.cfg]
2018-11-08 Add stand to bottom grip
    [controller_and_custom_bottom_grip.cfg, prototype_1.cfg, prototype_1_custom.cfg]
2018-11-12 Add models for custom strap, ready for printing
    [---threaded_bumper_top---.stl, ---vive_bumper_base_final---.stl, controller_and_custom_bottom_grip.cfg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]
2018-11-12 Reorganize folders
    [Asm1.cfg, controller_and_custom_bottom_grip.cfg, pillars_tower.cfg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]
2018-11-13 Simplify cornerns of custom_strap_bottom
    [custom_strap.cfg, custom_strap_bottom.stl]
2018-11-13 Add new alternative modeling of stand/bottom grip
    [base_stand_and_controller.cfg, bracketed_cylinder_and_controller.cfg, controller_and_custom_bottom_grip.cfg]
2018-11-14 Add test holes
    To be used in local hw store to choose adequate screw size for
    the custom strap holes.
    [test_hole_3_56mm.stl, test_hole_4mm.stl, test_hole_5mm.stl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]
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2018-11-19 Add symmetric padding around elipse base
    [bracketed_cylinder_and_controller.cfg]
2018-11-20 Create new assembly with slim custom parts
    [controller_and_custom_strap.cfg, prototype_1_custom_full.cfg]
2018-11-20 Add parts to connect strap to stand
    [custom_strap.cfg, prototype_1_custom_full.cfg]
2018-11-20 Reduce length of strip connecting strap and stand
    [prototype_1_custom_full.cfg]
2018-11-20 Add arduino and roundings to prototype 1
    [prototype_1_custom_full.cfg]
2018-11-20 Add test hole with 6.5mm diameter
    [test_hole_6_50mm.stl]
2018-11-21 Change holes to 6.6mm and add more roundings
    [prototype_1_custom_full.cfg]
2018-11-21 Add more surface and some blends to angled base
    [prototype_1_custom_full.cfg]
2018-11-21 Increase distance between screw holes and add nuts
    [prototype_1_custom_full.cfg]
2018-11-22 Add Prototype 0 to Prototype 1 with connections
    [prototype_1_custom_full.cfg]
2018-11-28 Update gcodes for arduino case
    [arduino_due_case_bottom.stl]
2018-11-28 Add support for weights on the tip of the feedback
    [prototype_1_custom_full.cfg]
2018-11-28 Add printing files for case top
    [arduino_due_case_top.stl]
2018-12-12 Add printing files and adaptations, simplify parts
    [adapter_vertical_to_horizontal_holes.stl, custom_strap_bottom.stl, custom_strap_top.stl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]
2018-12-12 Add custom tip adapter for 9v battery
    [adapter_vertical_to_horizontal_holes.stl, prototype_1_custom_full_simplified.cfg]
2018-12-12 Make angled base flush
    [prototype_1_custom_full_simplified.cfg]
2018-12-17 Remove material from angled base, print 9v box
    [adapter_strap_to_servo.stl, angled_base_29_degrees.stl, angled_base_29_degrees_copy.stl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]
2018-12-17 Add fastening mechanism for strap
    [prototype_1_custom_full_simplified.cfg]
2019-01-02 Fix oversized parts, add support test
    [prototype_1_custom_full_simplified.cfg]
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2019-01-03 Fix parts that were weak or wrongly sized
    [prototype_1_custom_full_simplified.cfg]
2019-01-03 Batch update printing files
    [S_angled_base_29_degrees_copy_2.curaproject.3mf, angled_base_29_degrees_copy_2.stl, disco_hub_bigger_hole.stl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]
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2019-01-31 Fix servos movement mapping from feedback pointer
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
